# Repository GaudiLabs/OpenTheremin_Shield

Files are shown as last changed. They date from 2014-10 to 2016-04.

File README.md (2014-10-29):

## Open.Theremin.UNO hardware description 

Schematics, printed circuit board (PCB) design, bill of materials (BOM) for the Open.Theremin.UNO arduino shield.
For software see separate git repository.

### Don't click on the files!
Click on the "Download ZIP" Button to the right or [Click here](https://github.com/GaudiLabs/OpenTheremin_Shield/archive/master.zip) 
Then unpack the archive.

### Open Source Theremin based on the Arduino Platform

Open.Theremin.UNO is an arduino shield to build the legendary music instrument invented by Leon Theremin back in 1920. The theremin is played with two antennas, one to control the pitch and one for volume. The electronic shield with two ports to connect those antennas comprises two heterodyne oscillators to measure the distance of the hand to the antenna when playing the instrument. The resulting signal is fed into the arduino. After linearization and filtering the arduino generates the instruments sound that is then played through a high quality digital analog audio converter on the board. The characteristics of the sound can be determined by a wave table on the arduino.

For more info on the open source project and on availability of ready made shield see:

http://www.gaudi.ch/OpenTheremin/

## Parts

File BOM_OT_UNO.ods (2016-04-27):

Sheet: Sheet1
Open.Thmeremin.UNO V2.0 Bill of Materials
Index | Quantity | Typ | Housing | Order No. Reichelt | Order No. Farnell @ 200 | Order No. Digikey http://www.digikey.ca/short/3qvv8w
IC1, IC2 | 2 | 4060D | SO-16 | SMD 4060 |  | 568-1460-5-ND (http://www.digikey.ca/product-detail/en/nxp-semiconductors/74HC4060D,652/568-1460-5-ND/763064)
IC3 | 1 | 4069D | SO-14 | SMD 4069 |  | 296-14126-1-ND (http://www.digikey.ca/product-detail/en/texas-instruments/CD4069UBNSR/296-14126-1-ND/525934)
IC4 | 1 | LM358D | SO-8 | LM 358 SMD |  | 497-1591-1-ND (http://www.digikey.ca/product-detail/en/stmicroelectronics/LM358DT/497-1591-1-ND/592083)
IC5 | 1 | 74AC74D | SO-14 | 74AC 74D-SMD |  | MC74AC74DR2GOSCT-ND (http://www.digikey.ca/product-detail/en/on-semiconductor/MC74AC74DR2G/MC74AC74DR2GOSCT-ND/1967099)
IC6 | 1 | MCP4921SO8 | SO-8 |  | 1332113 | MCP4921-E/SN-ND (http://www.digikey.ca/product-detail/en/microchip-technology/MCP4921-E%2FSN/MCP4921-E%2FSN-ND/716196)
Q1 | 1 | 7.3721MHz | HC49-SMD | 7,3728-HC49-SMD |  | XC1687CT-ND (http://www.digikey.ca/product-detail/en/ecs-inc/ECS-73-18-5PXEN-TR/XC1687CT-ND/2213839)
Q2 | 1 | 8MHz | HC49-SMD | 8,0000-HC49-SMD |  | XC1271CT-ND (http://www.digikey.ca/product-detail/en/ecs-inc/ECS-80-18-5PX-TR/XC1271CT-ND/827735)
LED1 | 1 | Green | LEDCHIPLED_0805 | SMD-LED 0805 GN |  | 160-1179-1-ND (http://www.digikey.ca/product-detail/en/lite-on-inc/LTST-C170GKT/160-1179-1-ND/269251)
LED2 | 1 | Yellow | LEDCHIPLED_0805 | SMD-LED 0805 GE |  | 160-1416-1-ND (http://www.digikey.ca/product-detail/en/lite-on-inc/LTST-C170KSKT/160-1416-1-ND/386780)
L1, L2 | 2 | 1000 uH |  |  | 1653708 | CM453232-102KLCT-ND (http://www.digikey.ca/product-detail/en/bourns-inc/CM453232-102KL/CM453232-102KLCT-ND/3437941)
C1, C2, C3, C4 | 4 | 33pF |  |  | 2392200 | 399-1115-1-ND (http://www.digikey.ca/product-detail/en/kemet/C0805C330J5GACTU/399-1115-1-ND/411390)
C24, C25 | 2 | 22pF |  | NPO-G0805 22P |  | 399-1113-1-ND (http://www.digikey.ca/product-detail/en/kemet/C0805C220J5GACTU/399-1113-1-ND/411388)
C5, C6 | 2 | 100pF |  |  | 2392180 | 399-1122-1-ND (http://www.digikey.ca/product-detail/en/kemet/C0805C101J5GACTU/399-1122-1-ND/411397)
C7 | 1 | 330pF |  | NPO-G0805 330P |  | 399-1130-1-ND (http://www.digikey.ca/product-detail/en/kemet/C0805C331J5GACTU/399-1130-1-ND/411405)
C8 | 1 | 220pF |  | NPO-G0805 220P |  | 399-1127-1-ND (http://www.digikey.ca/product-detail/en/kemet/C0805C221J5GACTU/399-1127-1-ND/411402)
C15, C18, C19, C20, C21, C22 C23 | 7 | 100nF |  |  | 2392344 | 399-1170-1-ND (http://www.digikey.ca/product-detail/en/kemet/C0805C104K5RACTU/399-1170-1-ND/411445)
C16 | 1 | 10nF |  |  | 2392340 | 399-1158-1-ND (http://www.digikey.ca/product-detail/en/kemet/C0805C103K5RACTU/399-1158-1-ND/411433)
C17 | 1 | 100uF | CPOL-EU153CLV-0505 | VF 100/6,3 K-C |  | 565-2519-1-ND (http://www.digikey.ca/product-detail/en/united-chemi-con/EMZA6R3ADA101ME61G/565-2519-1-ND/757680)
CT1, CT2 | 2 | 6.5-30pF |  |  | 9528660 | 490-7155-ND (http://www.digikey.ca/product-detail/en/murata-electronics-north-america/TZC3P300A110B00/490-7155-ND/2605011)
R1, R2, R5, R6 | 4 | 4.7MOhm |  |  | 2129403 | RHM4.70MAHCT-ND (http://www.digikey.ca/product-detail/en/rohm-semiconductor/KTR10EZPF4704/RHM4.70MAHCT-ND/1983987)
R3, R4 | 2 | 470 Ohm |  |  |  | 1276-5254-1-ND (http://www.digikey.ca/product-detail/en/samsung-electro-mechanics-america-inc/RC2012F471CS/1276-5254-1-ND/3968226)
R21 | 1 | 2.2kOhm |  |  | 2129138 | 1276-5290-1-ND (http://www.digikey.ca/product-detail/en/samsung-electro-mechanics-america-inc/RC2012F222CS/1276-5290-1-ND/3968262)
R7, R8 | 2 | 10kOhm |  |  | 2129195 | YAG1319CT-ND (http://www.digikey.ca/product-detail/en/yageo/RC0805FR-0710KP/YAG1319CT-ND/4935432)
R22 | 1 | 100kOhm |  | SMD-0805 100K | 2129276 | 1276-3512-1-ND (http://www.digikey.ca/product-detail/en/samsung-electro-mechanics-america-inc/RC2012F104CS/1276-3512-1-ND/3903615)
R24, R25 | 2 | 390Ohm |  |  | 2129080 | RHM390CHCT-ND (http://www.digikey.ca/product-detail/en/rohm-semiconductor/MCR10ERTF3900/RHM390CHCT-ND/4084817)
X1 | 1 | MJ4435-R1503_03 | MJ4435-R |  | 1638670 | CP-3523SJCT-ND - not exactly the same footprint!!! (http://www.digikey.ca/product-detail/en/cui-inc/SJ-3523-SMT-TR/CP-3523SJCT-ND/669704)
PINS | 1 | Pinheaders 36x |  | SL 1X36G 2,54 |  | 929400E-01-36-ND (http://www.digikey.ca/product-detail/en/3m/929400-01-36-RK/929400E-01-36-ND/1093569)
S1 | 1 | BUTTON |  | TASTER 9314 |  | FSM2JSMAA-ND (http://www.digikey.ca/product-detail/en/te-connectivity-alcoswitch-switches/FSM2JSMAA/FSM2JSMAA-ND/2400228)
PCB | 1 | Circuit Board UNO
POT1, POT2 | 2 | EVUF3A |  | RK09K113-LIN10K
Knob | 2 |  |  | KNOPF 10-150B
CV_JP | 1 |  |  | JUMPER 2,54 R
LED 5mm | 1 |  |  | LED Blue
U$1 | 1 | ARDUINO-UNO
Bestellkosten | 1
Lötpaste | 1 | Lötpaste RohS, 120g, 30ml |  | Fürtronic Art. 2296
Shipping Europe | 1
Shipping other | 0
Packaging Couvert | 1
Packaging Bag | 1 |  |  | ESD BEUTEL-P 150
Packaging Bag small | 2
Adress Pocket | 1
Screwdriver | 1
Antenne Aluminum 5mm | 2
Antenna Plug Screwing | 2 |  |  | VST 20
Antenna Plug Standard | 2 |  |  | BS 40SA RT
Schrauben M3x6 | 2 |  |  | BN1435.03006
Schrauben M3x10 | 2 |  |  | BN1435.03010
Spacer | 2 | Metall, 6-Kant, M3, 8mm |  | DI 8MM
Unterlags | 2 |  |  | SKZ 3,2-100
Plexi Base | 1 |  |  | GS Allround 1H20
Tesa Tape | 1 |  |  | TESA 55733
Antenna Extension Plug | 1 |  |  | VST 100

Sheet: Sheet2
JUMPER 2,54 R | 90
SMD 4069 | 150
LM 358 SMD | 150
74AC 74D-SMD | 150
7,3728-HC49-SMD | 150
8,0000-HC49-SMD | 150
SMD-LED 0805 GN | 150
NPO-G0805 330P | 150
NPO-G0805 220P | 150
VF 100/6,3 K-C | 150
SL 1X36G 2,54 | 150
TASTER 9314 | 150
ESD BEUTEL-P 150 | 150
RK09K113-LIN10K | 180
KNOPF 10-150B | 180
BS 40SA RT | 180
DI 8MM | 180
SKZ 3,2-100 | 180
SMD 4060 | 300
NPO-G0805 22P | 300

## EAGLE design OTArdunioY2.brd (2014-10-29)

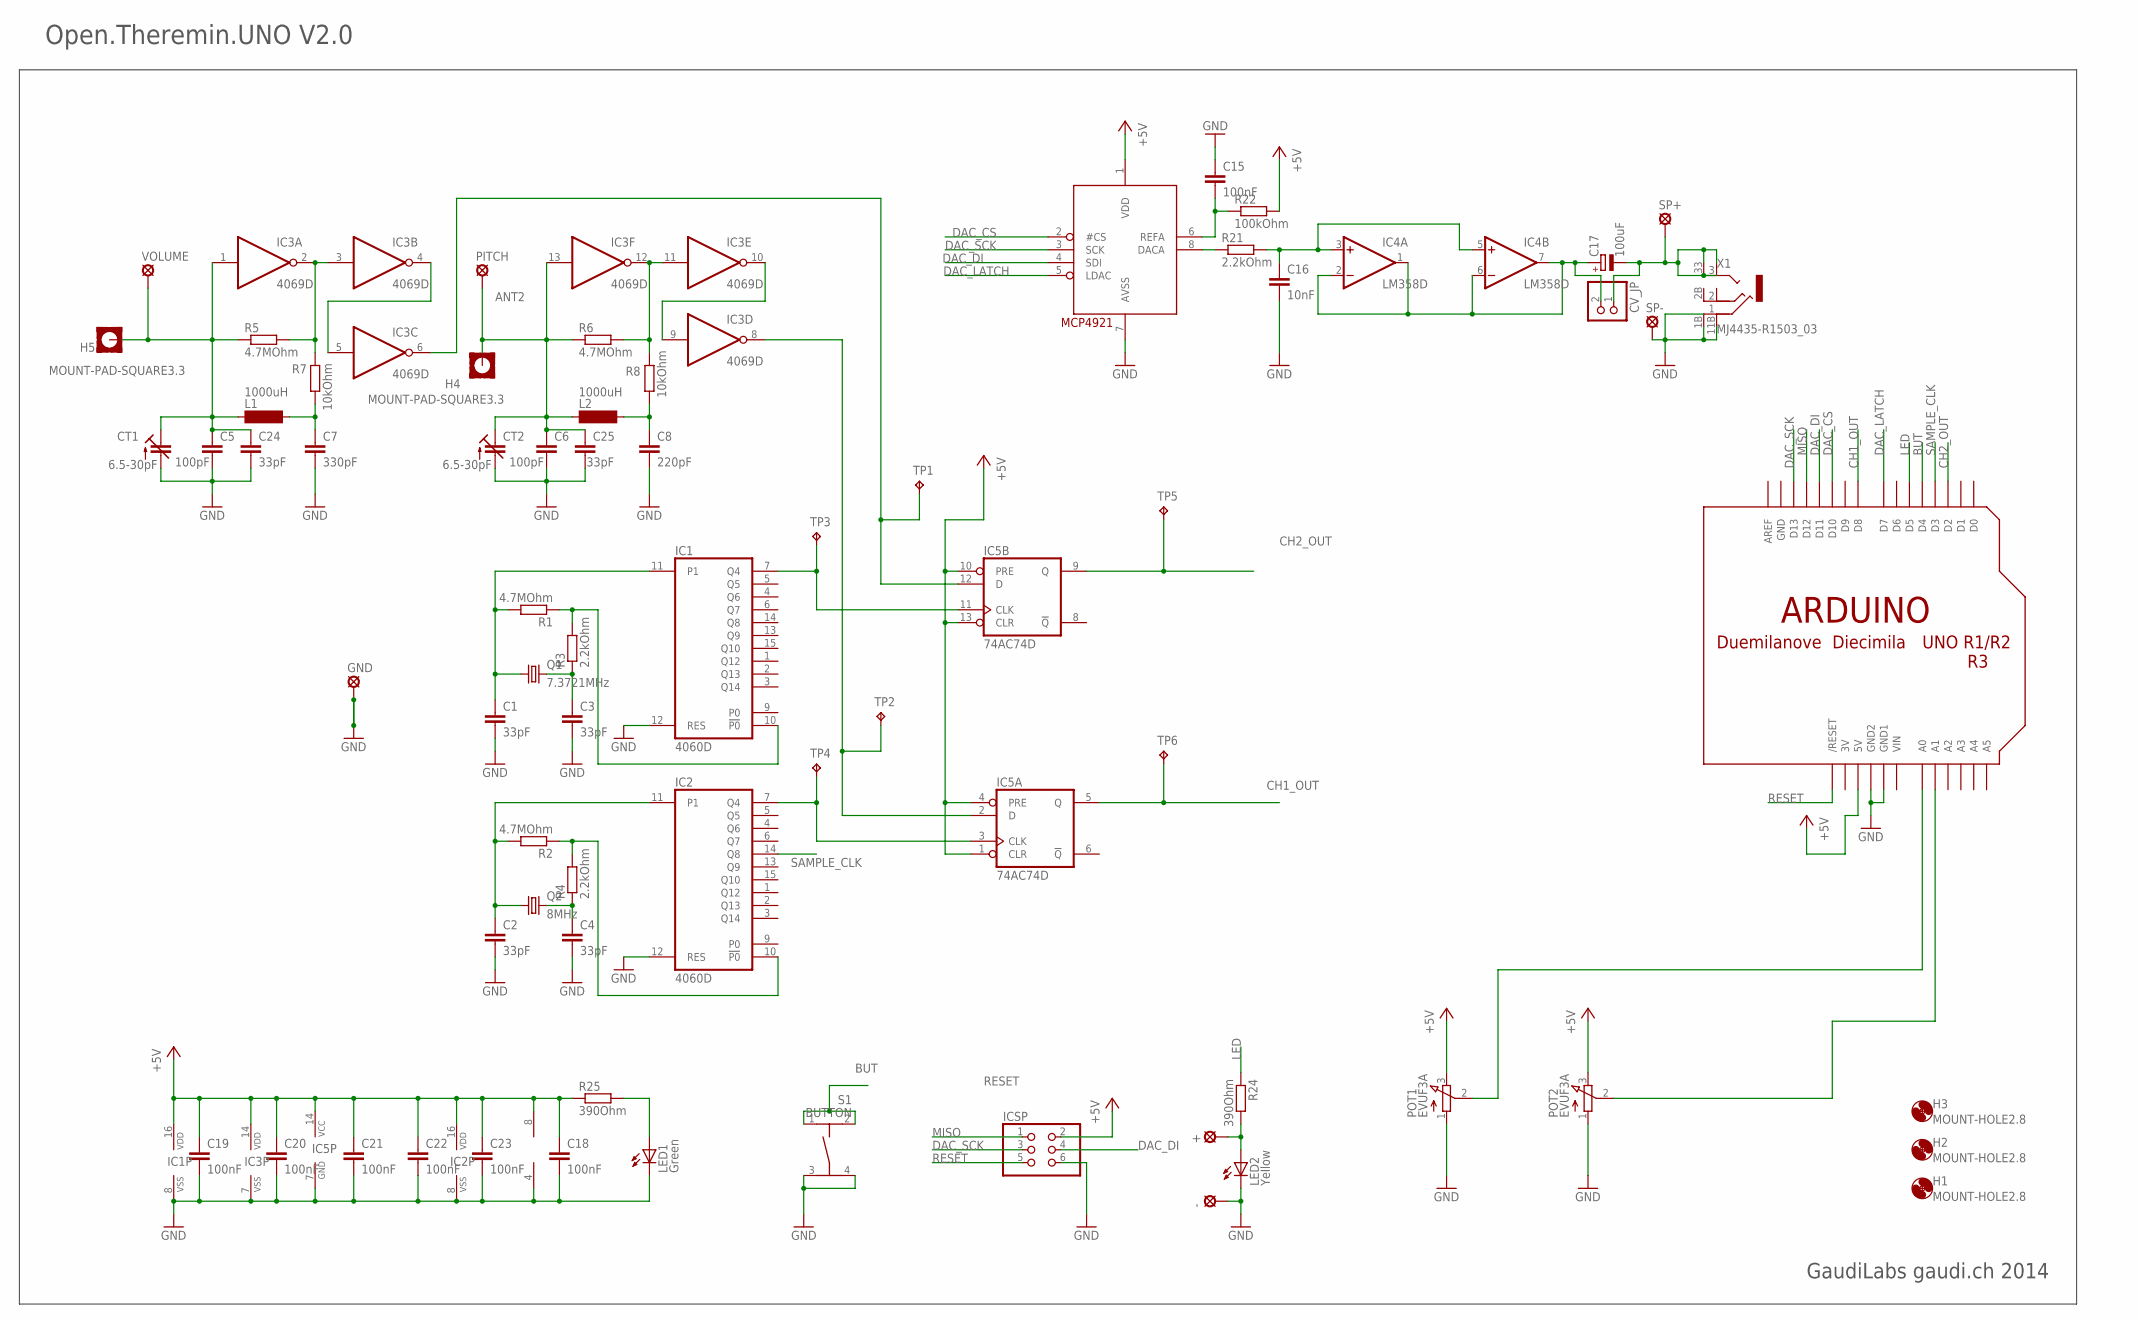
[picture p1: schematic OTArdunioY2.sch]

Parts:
+: LSP11
-: LSP11
C1, C2, C3, C4, C24, C25: 33pF; C0805
C5, C6: 100pF; C0805
C7: 330pF; C0805
C8: 220pF; C0805
C15, C18, C19, C20, C21, C22, C23: 100nF; C0805
C16: 10nF; C0805
C17: 100uF; 153CLV-0505
CT1, CT2: 6.5-30pF; CTRIMTZBX4
CV_JP: PINHD-1X2; 1X02
GND: SE14
H1, H2, H3: MOUNT-HOLE2.8; 3,3
H4, H5: MOUNT-PAD-SQUARE3.3; 3,3-PAD-SQUARE
IC1, IC2: 4060D; SO16
IC3: 4069D; SO14
IC4: LM358D; SO08
IC5: 74AC74D; SO14
IC6: MCP4921SO8; SO08
ICSP: PINHD-2X3; 2X03
L1, L2: 1000uH; MS42
LED1: Green; CHIPLED_0805
LED2: Yellow; CHIPLED_0805
PITCH: SE14
POT1, POT2: EVUF3A; EVUF
Q1: 7.3721MHz; CSM-7X-DU
Q2: 8MHz; CSM-7X-DU
R1, R2, R5, R6: 4.7MOhm; M0805
R3, R4, R21: 2.2kOhm; M0805
R7, R8: 10kOhm; M0805
R22: 100kOhm; M0805
R24, R25: 390Ohm; M0805
S1: BUTTON; TASTER-9314_SMD
SP+: LSP11
SP-: LSP11
TP1, TP2, TP3, TP4, TP5, TP6: TPTP15R; TP15R
U$1: ARDUINODUEMILANOVE-NODIM; ARDUINO-NODIM
VOLUME: SE14
X1: MJ4435-R1503_03; 1503_02

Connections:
3V: U$1.3V
+5V: C18.1, C19.1, C20.1, C21.1, C22.1, C23.1, IC1.16 (VDD), IC2.16 (VDD), IC3.14 (VDD), IC4.8 (V+), IC5.1 (CLR), IC5.4 (PRE), IC5.10 (PRE), IC5.13 (CLR), IC5.14 (VCC), IC6.1 (VDD), ICSP.2, POT1.3 (E), POT2.3 (E), R22.2, R25.1, U$1.5V
ANT2: C6.1, C25.1, CT2.1 (E), H4.B3,3, IC3.13 (I), L2.1, PITCH.MP, R6.1
BUT: S1.1, S1.2, U$1.D4
CH1_OUT: IC5.5 (Q), TP6.TP, U$1.D8
CH2_OUT: IC5.9 (Q), TP5.TP, U$1.D2
DAC_CS: IC6.2 (#CS), U$1.D10
DAC_DI: IC6.4 (SDI), ICSP.4, U$1.D11
DAC_LATCH: IC6.5 (LDAC), U$1.D7
DAC_SCK: IC6.3 (SCK), ICSP.3, U$1.D13
GND: -.MP, C1.2, C2.2, C3.2, C4.2, C5.2, C6.2, C7.2, C8.2, C15.1, C16.2, C18.2, C19.2, C20.2, C21.2, C22.2, C23.2, C24.2, C25.2, CT1.2 (A), CT2.2 (A), GND.MP, IC1.8 (VSS), IC1.12 (RES), IC2.8 (VSS), IC2.12 (RES), IC3.7 (VSS), IC4.4 (V-), IC5.7 (GND), IC6.7 (AVSS), ICSP.6, LED1.C, LED2.C, POT1.1 (A), POT2.1 (A), S1.3, S1.4, SP-.MP, U$1.GND, U$1.GND1, U$1.GND2, X1.1 (1_1), X1.1B (1_3), X1.11B (1_4)
LED: R24.1, U$1.D5
MISO: ICSP.1, U$1.D12
unnamed: C1.1, IC1.11 (P1), Q1.1, R1.2
unnamed: C17.-, CV_JP.1, SP+.MP, X1.3 (3_1), X1.3B (3_2), X1.33 (3_3), X1.33B (3_4)
unnamed: IC1.10 (!P0), R1.1, R3.2
unnamed: POT2.2 (S), U$1.A1
unnamed: +.MP, LED2.A, R24.2
unnamed: C3.1, Q1.2, R3.1
unnamed: C2.1, IC2.11 (P1), Q2.1, R2.2
unnamed: LED1.A, R25.2
unnamed: C4.1, Q2.2, R4.1
unnamed: IC2.10 (!P0), R2.1, R4.2
unnamed: C5.1, C24.1, CT1.1 (E), H5.B3,3, IC3.1 (I), L1.1, R5.1, VOLUME.MP
unnamed: IC3.6 (O), IC5.12 (D), TP1.TP
unnamed: C7.1, L1.2, R7.1
unnamed: POT1.2 (S), U$1.A0
unnamed: C17.+, CV_JP.2, IC4.1 (OUT), IC4.2 (-IN), IC4.6 (-IN), IC4.7 (OUT)
unnamed: IC3.8 (O), IC5.2 (D), TP2.TP
unnamed: C8.1, L2.2, R8.1
unnamed: IC1.7 (Q4), IC5.11 (CLK), TP3.TP
unnamed: IC2.7 (Q4), IC5.3 (CLK), TP4.TP
unnamed: C15.2, IC6.6 (REFA), R22.1
unnamed: IC6.8 (DACA), R21.1
unnamed: IC3.11 (I), IC3.12 (O), R6.2, R8.2
unnamed: IC3.2 (O), IC3.3 (I), R5.2, R7.2
unnamed: IC3.4 (O), IC3.5 (I)
unnamed: C16.1, IC4.3 (+IN), IC4.5 (+IN), R21.2
unnamed: IC3.9 (I), IC3.10 (O)
RESET: ICSP.5, U$1.RESET (/RESET)
SAMPLE_CLK: IC2.14 (Q8), U$1.D3
VIN: U$1.VIN

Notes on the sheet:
RESET
Open.Theremin.UNO V2.0
GaudiLabs gaudi.ch 2014

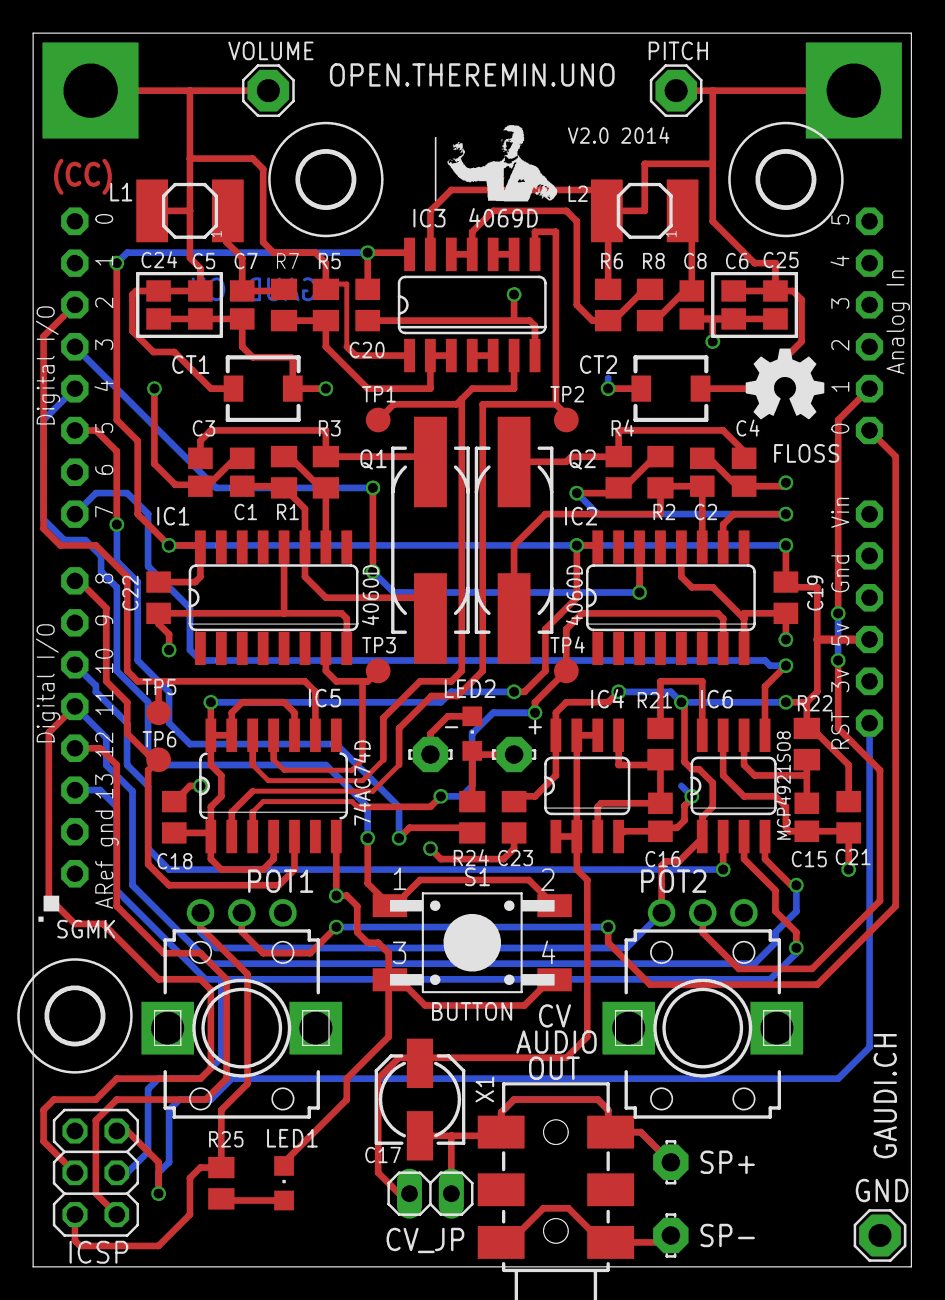
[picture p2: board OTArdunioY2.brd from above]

Board: 4 copper layers, 53.3 x 74.9 mm, 70 parts (0 on the bottom side), 40 nets.

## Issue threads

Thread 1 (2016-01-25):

CD4060 Counters

jwettroth, 2016-01-25:
The counter used in this circuit are only rated for 3.5 MHz at 5v, they will run up to 12 MHz at 15v.  I would however recommend using 74HC4060 counters, can easily handle these frequencies and are pin compatible, etc.

GaudiLabs, 2016-01-25:
Hi

You are right, these chips are overclocked - still works. I changed to
74HC4060 on the newes series. Guess I should update the schematic and
BOM on that.

Thanks ,
Urs

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

--

========= GaudiLabs =========
Urs Gaudenz
Email:   urs@gaudi.ch
Mobile:  +41 76 480 1772

Neustadtstrasse 7
CH-6003 Luzern
Switzerland

www.gaudi.ch
www.facebook.com/mrgaudi
=============================

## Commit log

2014-10-29 Version 2.0 - first batch design
    [OTArdunioY2.brd, OTArdunioY2.sch]
2014-10-29 Version 2.0
    [BOM_OT_UNO.ods]
2015-06-12 Updated the bill of materials
    [BOM_OT_UNO.ods]
2015-06-12 Updated the Bill of Materials (BOM)
    [BOM_OT_UNO.ods]
2015-06-12 Updated the Bill of Materials (BOM) with new coil.
    [BOM_OT_UNO.ods]
2016-02-22 Added Mechanical Drawings
    for Antenna and extension Parts
2016-03-23 updated BOM with digikey parts
    [BOM_OT_UNO.ods]
